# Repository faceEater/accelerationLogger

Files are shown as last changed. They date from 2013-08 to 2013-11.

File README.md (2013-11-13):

A pre-release of my acceleration logger files for critique
	Not guaranteed to work!
	All licensed under CC-BY-SA 3.0

Summary:
    Dimensions: 1.25in x 2.5in * 1in
    Induction charged. Supercapacitor is charged by LT1618 from the coil(P2) and Bridge rectifier.
    Optical communications, serial@56kbaud
    Mating charging/comms circuit not yet designed
    Updatable firmware
    8Mbyte onboard flash
    Charges in <5 minutes with coil supplying 5v at a yet to be determined current (depends on charger)
    Powered from 5V, 5F supercap with LT1615-1 SEPIC Converter
    Linear postregulator for low noise
    Quiescent current < 200uA
    May or may not be potted, depending on requirements. Potted version is watertight.
    P1 for programming AVR + 2 GPIO & Serial
    Low power: <3mA at 1ksps for >30min battery life
    Fast sampling: 3 axis sampling at 1ksps/Axis
    3-axis
    200g full-scale, 100mg resolution 16-200g
    Sub 16-g resolution better than 5 mg
    4-layer board, believed to meet OSH park's design rules
    (Mostly) Arduino-compatible
    Atmega1284p processor
    Open Source -- CC-BY-SA 3.0

Github: https://github.com/faceEater/accelerationLogger

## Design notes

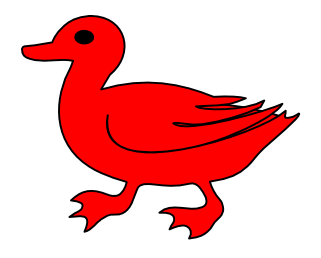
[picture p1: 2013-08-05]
Red_duck.png

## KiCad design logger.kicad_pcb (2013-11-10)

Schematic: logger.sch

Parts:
C2, C3: 22pf; SM0603_Capa
C4: 1uF; SM0603_Capa
C5, C12: 4.7u; SM0805
C6, C10, C27, C28: 1u; SM0603_Capa
C7: 4.7pF; SM0603_Capa
C8: .1u; SM0603_Capa
C9, C11, C13, C14, C29: 10u; SM0805
C23, C24, C25: 1n; SM0603_Capa
C26: C; SM0603_Capa
C30: 1u
D1: DIODESCH; SOD323
IC1: ATMEGA1284P-A; TQFP44
L1, L2, L5: 10u; SM2010
P1: CONN_5X2; PIN_ARRAY_5x2
Q1: MOS_P
R1, R5, R6, R7, R8, R9, R10, R12, R15, R18: 100k; SM0603
R2, R3: 1M; SM0603
R4: 560k; SM0603
R11, R30: 1; SM0603
R13, R14, R16: 196k; SM0603
R17: 180k; SM0603
R20: 1M
R31: 1k
U1: LT1615-1; SOT23-5
U2: SST25VF064C
U3: MCP6054; SO14N
U4: MAX11613; uMAX8
U5: TPS7703X; SOT23-5
U6: ADXL337; LFCSP8
U7: LIS3DSH; LGA16
X1: CRYSTAL; XTAL_DFN_CTS403

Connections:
3V3: C4.2, C7.1, C9.1, C10.1, C27.2, C28.2, C30.1, D1.2 (K), IC1.5 (VCC), IC1.17 (VCC), IC1.27 (AVCC), IC1.38 (VCC), L5.1, P1.2, R3.1, R5.2, R6.2, R12.2, U2.3 (!WP), U2.7 (!RESET), U2.8 (Vcc), U7.1 (Vdd_IO); also elsewhere on the board
3V3_Analog: C8.1, C13.1, Q1.D, R18.1, U3.4 (V+), U4.4 (Ain3), U6.14 (Vs), U6.15 (Vs)
3V3_Analog_Unswitched: C11.1, C14.2, Q1.S, R7.2, R8.2, R20.1, R30.2, U4.5 (V+), U7.8 (CS), U7.14 (Vdd), U7.15 (Res)
GND: C2.1, C3.1, C4.1, C5.2, C8.2, C9.2, C10.2, C11.2, C12.2, C13.2, C14.1, C23.2, C24.2, C25.1, C26.2, C27.1, C28.1, C29.2, C30.2, IC1.6 (GND), IC1.18 (GND), IC1.28 (GND), IC1.39 (GND), L2.2, P1.6, R4.2, R13.2, R14.2, R15.2, R17.2, U1.2 (GND), U2.4 (GND), U3.11 (GND), U4.6 (Gnd), U5.2 (GND), U5.3 (!EN), U6.2 (ST), U6.6 (GND), U6.7 (GND), U7.5 (GND), U7.7 (SEL), U7.10 (Res), U7.12 (GND), U7.13 (GND), U7.16 (GND); also elsewhere on the board
unnamed: C2.2, IC1.7 (XTAL2), R2.1, X1.2
unnamed: C3.2, IC1.8 (XTAL1), R2.2, X1.1
unnamed: C6.1, L1.2, U1.1 (SW)
unnamed: C6.2, D1.1 (A), L2.1
unnamed: C7.2, R3.2, R4.1, U1.3 (FB)
unnamed: C12.1, R11.2
unnamed: C23.1, R10.1, U6.4 (Yout)
unnamed: C24.1, R9.1, U6.16 (Zout)
unnamed: C25.2, R16.1, U6.5 (Xout)
unnamed: C26.1, IC1.29 (AREF)
unnamed: C29.1, L5.2, U5.1 (IN)
unnamed: IC1.1 ((PCINT13/MOSI)PB5), P1.4, R12.1, U2.5 (SI)
unnamed: IC1.2 ((PCINT14/MISO)PB6), P1.1, R6.1, U2.2 (SO)
unnamed: IC1.3 ((PCINT15/SCK)PB7), P1.3, R5.1, U2.6 (SCK)
unnamed: IC1.4 (~RESET), P1.5, R1.1
unnamed: IC1.19 ((PCINT16/SCL)PC0), R7.1, U4.8 (SCL), U7.4 (SCL)
unnamed: IC1.20 ((PCINT17/SDA)PC1), R8.1, U4.7 (SDA), U7.6 (SDA)
unnamed: IC1.23 ((PCINT20/TDO)PC4), U7.11 (INT1)
unnamed: IC1.24 ((PCINT21/TDI)PC5), R31.2
unnamed: IC1.30 ((PCINT7/ADC7)PA7), P1.10
unnamed: IC1.31 ((PCINT6/ADC6)PA6), P1.9
unnamed: IC1.44 ((PCINT12/OC0B/~SS~)PB4), U2.1 (!CS)
unnamed: Q1.G, R20.2, R31.1
unnamed: R10.2, R14.1, U3.12 (VinC+)
unnamed: R11.1, R30.1, U5.5 (OUT)
unnamed: R9.2, R13.1, U3.10 (VinD+)
unnamed: R15.1, R16.2, U3.3 (InA+)
unnamed: R17.1, R18.2, U3.5 (VinB+)
unnamed: U3.1 (VoutA), U3.2 (InA-), U4.1 (Ain0)
unnamed: U3.6 (VinB-), U3.7 (VoutB)
unnamed: U3.8 (VoutD), U3.9 (VinD-), U4.3 (Ain2)
unnamed: U3.13 (VinC-), U3.14 (VoutC), U4.2 (Ain1)
RX: IC1.9 ((PCINT24/RXD0)PD0), P1.8; also elsewhere on the board
Reset: R1.2; also elsewhere on the board
TX: IC1.10 ((PCINT25/TXD0)PD1), P1.7; also elsewhere on the board
Vcap: C5.1, L1.1, U1.4 (!SHDN), U1.5 (Vin); also elsewhere on the board
Vmon: IC1.37 ((PCINT0/ADC0)PA0); also elsewhere on the board

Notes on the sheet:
1% or better for FB resistors
Select TPS77033 closest to but not exceeding .1v less than the LT1651 output (Or tweak FB resistors)
Rugged 250g, 3axis, 1Ksps acceleration logger: 4Mbyte flash, 5v 5F Supercap
1-6:ISP 7-8:TX,RX 9-10: GPIO
Using linear reg for noise reduction: do not substitute!
OSHW CC-BY-SA 3.0

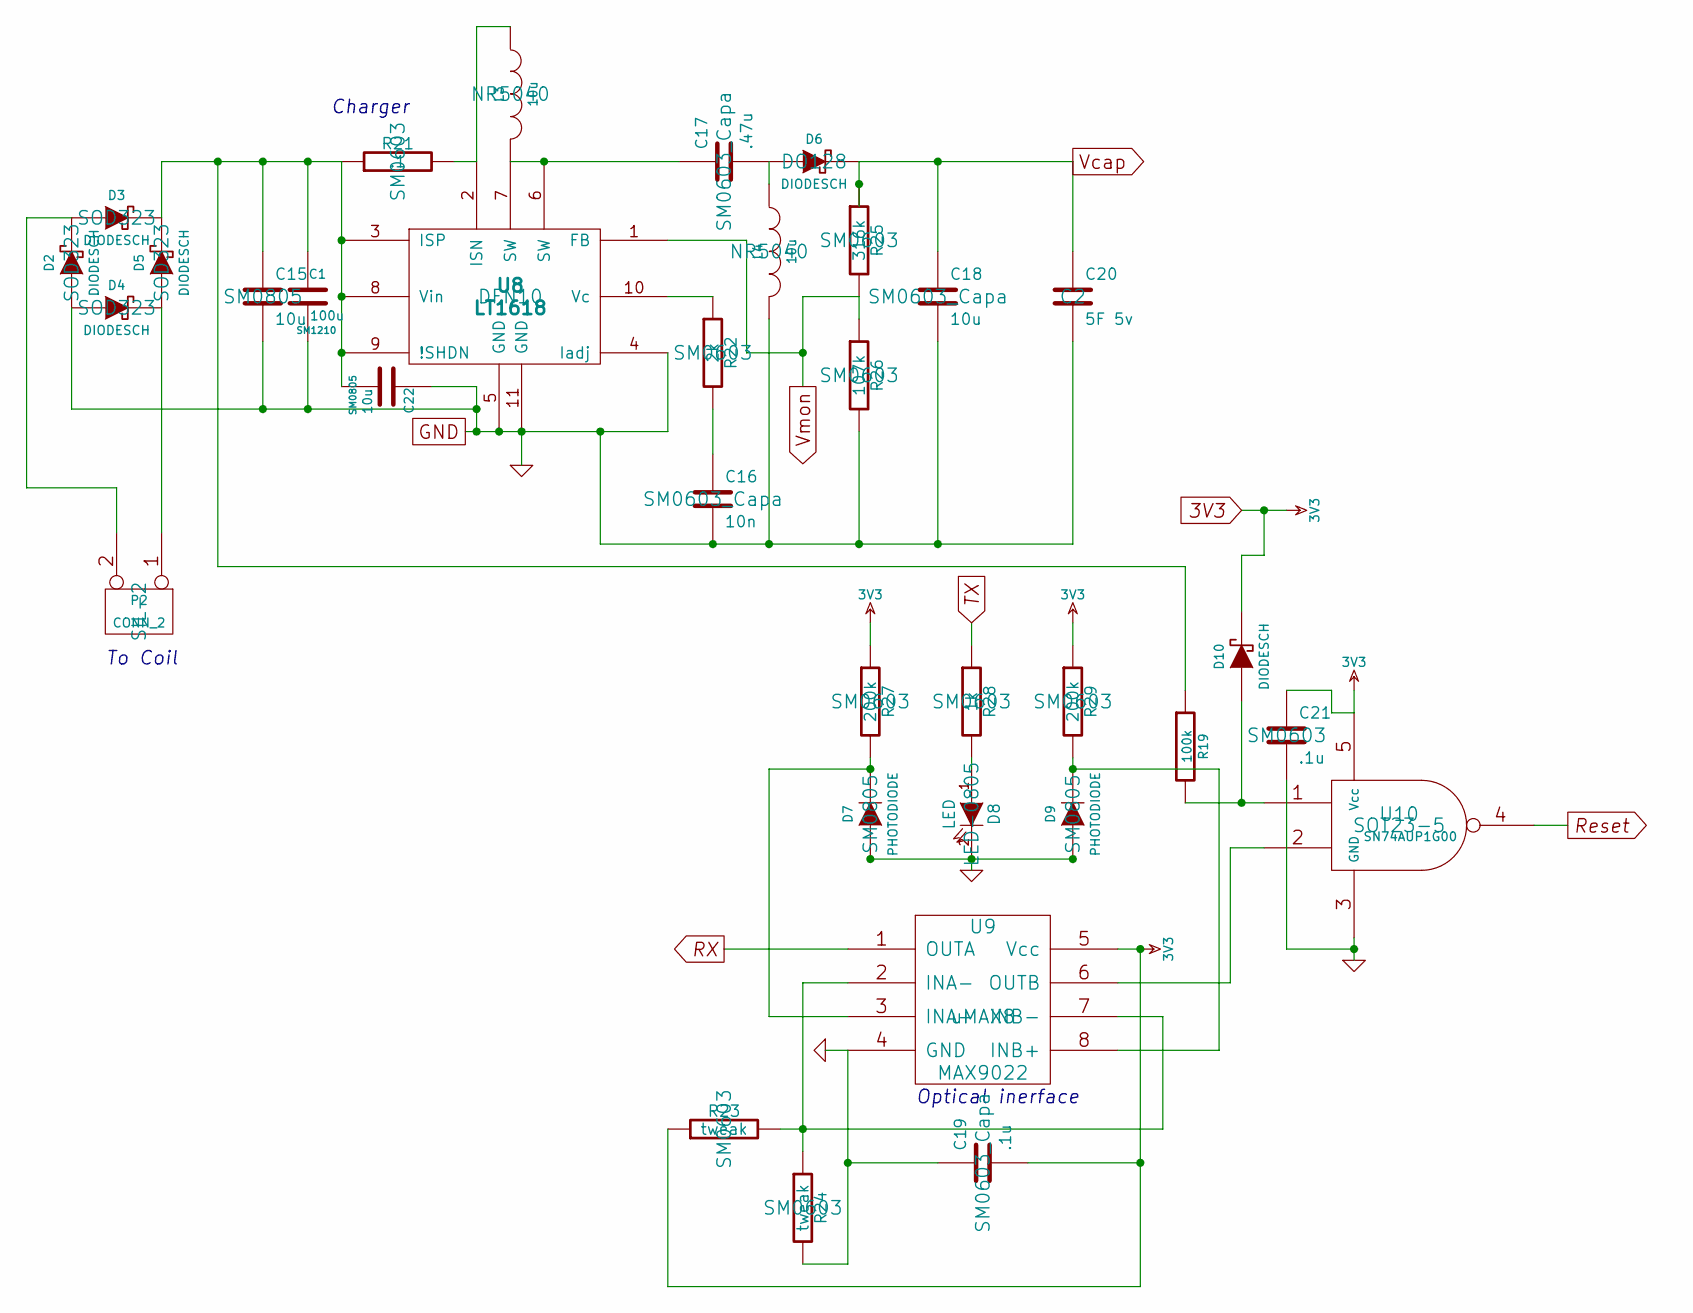
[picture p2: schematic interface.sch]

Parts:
C1: 100u; SM1210
C15, C22: 10u; SM0805
C16: 10n; SM0603_Capa
C17: .47u; SM0603_Capa
C18: 10u; SM0603_Capa
C19: .1u; SM0603_Capa
C20: 5F 5v; C2
C21: .1u; SM0603
D2, D3, D4, D5: DIODESCH; SOD323
D6: DIODESCH; DO128
D7, D9: PHOTODIODE; SM0805
D8: LED; LED-0805
D10: DIODESCH
L3, L4: 10u; NR5040
P2: CONN_2; SIL-2
R19: 100k
R21: .1; SM0603
R22: 2k; SM0603
R23, R24: tweak; SM0603
R25: 316k; SM0603
R26: 107k; SM0603
R27, R29: 200k; SM0603
R28: 1k; SM0603
U8: LT1618; DFN10
U9: MAX9022; uMAX8
U10: SN74AUP1G00; SOT23-5

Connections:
3V3: C19.2, C21.1, D10.2 (K), R23.1, R27.1, R29.1, U9.5 (Vcc), U10.5 (Vcc); also elsewhere on the board
GND: C1.2, C15.2, C16.2, C18.2, C19.1, C20.2, C21.2, C22.1, D2.1 (A), D4.1 (A), D7.1 (A), D8.2 (K), D9.1 (A), L4.2, R24.2, R26.2, U8.4 (Iadj), U8.5 (GND), U8.11 (GND), U9.4 (GND), U10.3 (GND); also elsewhere on the board
unnamed: C1.1, C15.1, C22.2, D3.2 (K), D5.2 (K), R19.1, R21.1, U8.3 (ISP), U8.8 (Vin), U8.9 (!SHDN)
unnamed: C16.1, R22.2
unnamed: C17.1, L3.2, U8.6 (SW), U8.7 (SW)
unnamed: C17.2, D6.1 (A), L4.1
unnamed: D2.2 (K), D3.1 (A), P2.2 (PM)
unnamed: D4.2 (K), D5.1 (A), P2.1
unnamed: D7.2 (K), R27.2, U9.3 (INA+)
unnamed: D8.1 (A), R28.2
unnamed: D9.2 (K), R29.2, U9.8 (INB+)
unnamed: D10.1 (A), R19.2, U10.1
unnamed: L3.1, R21.2, U8.2 (ISN)
unnamed: R22.1, U8.10 (Vc)
unnamed: R23.2, R24.1, U9.2 (INA-), U9.7 (INB-)
unnamed: U9.6 (OUTB), U10.2
RX: U9.1 (OUTA); also elsewhere on the board
Reset: U10.4; also elsewhere on the board
TX: R28.1; also elsewhere on the board
Vcap: C18.1, C20.1, D6.2 (K), R25.1; also elsewhere on the board
Vmon: R25.2, R26.1, U8.1 (FB); also elsewhere on the board

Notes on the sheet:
To Coil
Optical inerface
Charger

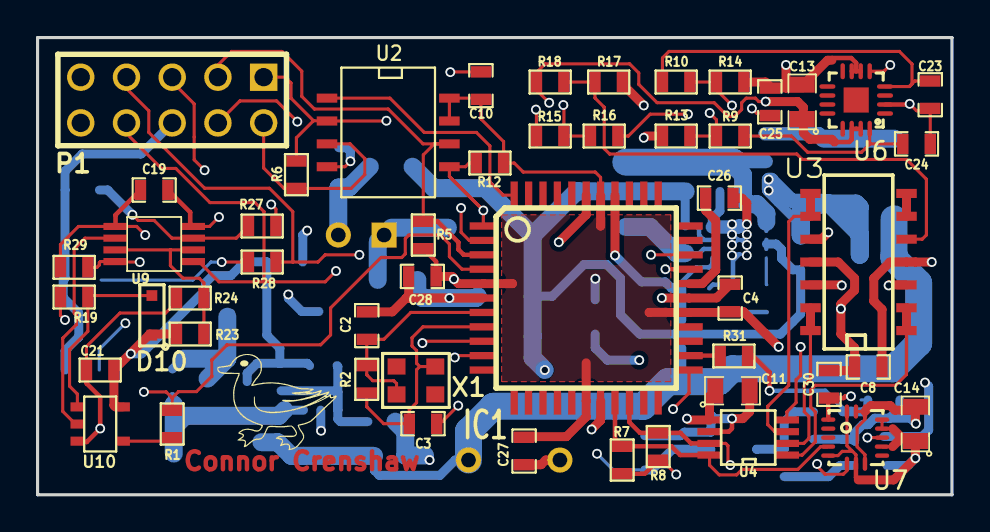
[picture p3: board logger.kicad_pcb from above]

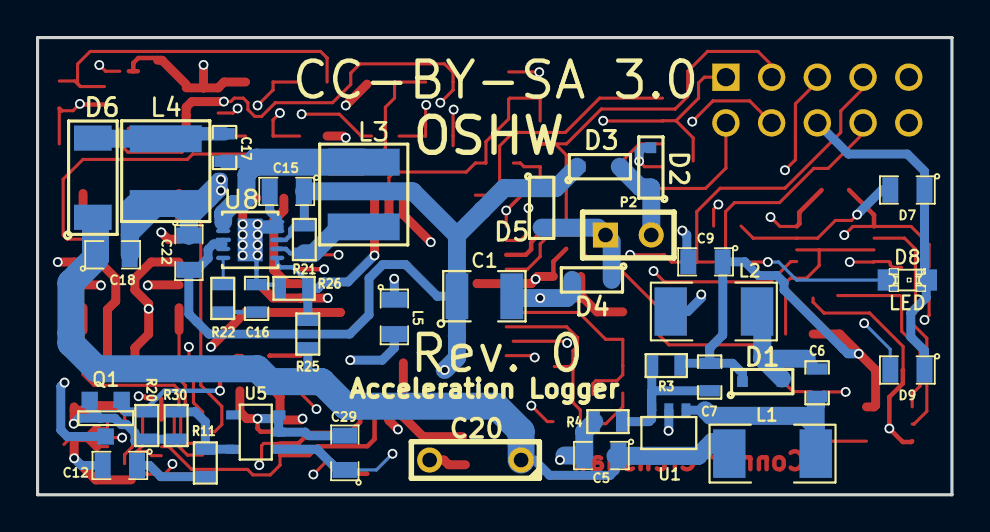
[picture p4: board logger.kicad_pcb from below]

Board: 4 copper layers, 50.8 x 25.4 mm, 92 parts (41 on the bottom side), 55 nets.

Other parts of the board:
VAL: DUCK

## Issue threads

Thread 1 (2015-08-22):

DFN10 KiCad module pin numbering wrong: should be CCW

bootchk, 2015-08-22:
Pin 1 on the actual part is marked by a cutout on pad 11 or by a dot graphic.  Your KiCad footprint should have similar marks.

Looking from the top, you should be able to put pin 1 in the upper left and pins should be numbered CCW from there.  Yours is wrong: reversed.

faceEater, 2015-08-23:
Sorry, the repo is horribly out-of date. I fixed this issue before my first board spin, and will try to get the updates organized so that I can upload them when time is available.

bootchk, 2015-08-23:
No problem.  I created my own footprint.  I found many variants of "DFN10".
